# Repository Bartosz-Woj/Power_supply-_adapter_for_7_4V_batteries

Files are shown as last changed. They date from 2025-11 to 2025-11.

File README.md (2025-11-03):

# Custom Power Supply Adapter for 7.4V batteries

## Project Description

The idea of this project is to create a **simple adapter** that allows using a **9 V (or higher)** DC power source instead of the original **7.4 V Li-ion battery** — specifically for the **Panasonic Lumix G7 camera**, using the **DMW-DCC8 DC coupler**.

This solution provides a regulated **8.55 V / 2 A** output suitable for continuous camera operation without relying on battery power.

This PCB can be used to replace a battery/accumulator in other similar applications.

---

## Technical Specifications

| Parameter | Description |
| --- | --- |
| **Input Voltage**  | 9 V – 20 V DC |
| **Output Voltage** | 8.55 V DC |
| **Output Current** | 2 A (max) |
| **Protection** | Overcurrent fuse and ESD protection |
| **Connector** | Screw terminal connector (raster 5mm) |

---

## Battery Voltage Background

A typical **2S Li-ion battery pack** (used in cameras like the Lumix G7) has a **nominal voltage of 7.4 V**, but it varies depending on the charge level:

| Battery State | Approx. Voltage |
| --- | --- |
| Fully Discharged | 6.0 V |
| Nominal | 7.4 V |
| Fully Charged | 8.4 V |

Initially, a resistor **R6** (8.66 kOhm) was selected to provide an output of **7.4V**, targeting a nominal 7.4 V equivalent output.

However, this voltage caused the camera to display the error:

> _"This battery cannot be used."_

and automatically power off after a few seconds.

After further research and forum discussions [[thread 1](https://www.dpreview.com/forums/post/59409259)] [[thread 2](https://dprevived.com/t/panasonic-s-series-standby-power-updated-with-s5m2/4551/)], it was discovered that the **Lumix G7** expects a slightly higher voltage (over 8.4V) to correctly identify the source as an **external power supply** rather than a battery. The manufacturer's documentation did not specify the allowable maximum supply voltage. Therefore, it was decided to set the threshold only slightly above the maximum cell voltage.

Currenct consumption was checked with usage of laboratory power supply.The average current consumption is 0.3A, but momentary peaks, especially during startup and photo taking, reach above 1A.

---

## Adjustment of output voltage

The output voltage is determined by a resistor divider network:

$$
V_{\text{out}} = V_{\text{ref}}\left(1 + \dfrac{R_5}{R_6}\right)
$$

For used step down converter (TPS54202):
$$ V\_{ref} = 0.596\,V $$

Example values:
| R5 | R6 | Output voltage |
| --- | ---- | --- |
| 100k | 8.66k | 7.4V |
| 100k | 7.5k | 8.55V |

** Note:** The TVS diode's operating voltage sets the maximum output voltage at 8.55V.
---

## 📸 Photos

- **📷 Project Overview:**  
  Overview Photo

- **🔌 Circuit Board / PCB:**  
  PCB Photo

---

## Author

- **Project by:** Bartosz-Woj (Bartosz Wojciechowski)
- **Date:** 03.11.2025

---

## Disclaimer

> ⚠️ **Important Notice**

This project is a **custom-made modification** and **not approved by Panasonic** or any official manufacturer.  
Using this power adapter **may void your warranty** and **can potentially damage your device** if built or used incorrectly.

The author of this project **does not take responsibility** for any **damage, data loss, or warranty issues** resulting from the use of this adapter.

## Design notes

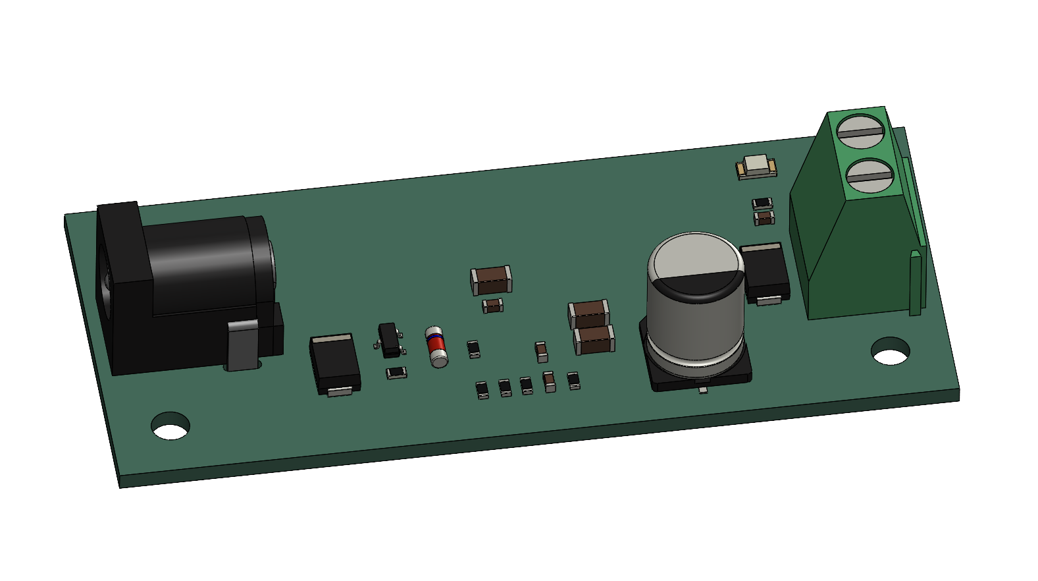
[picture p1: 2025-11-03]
photos/visualisation_PCB.png

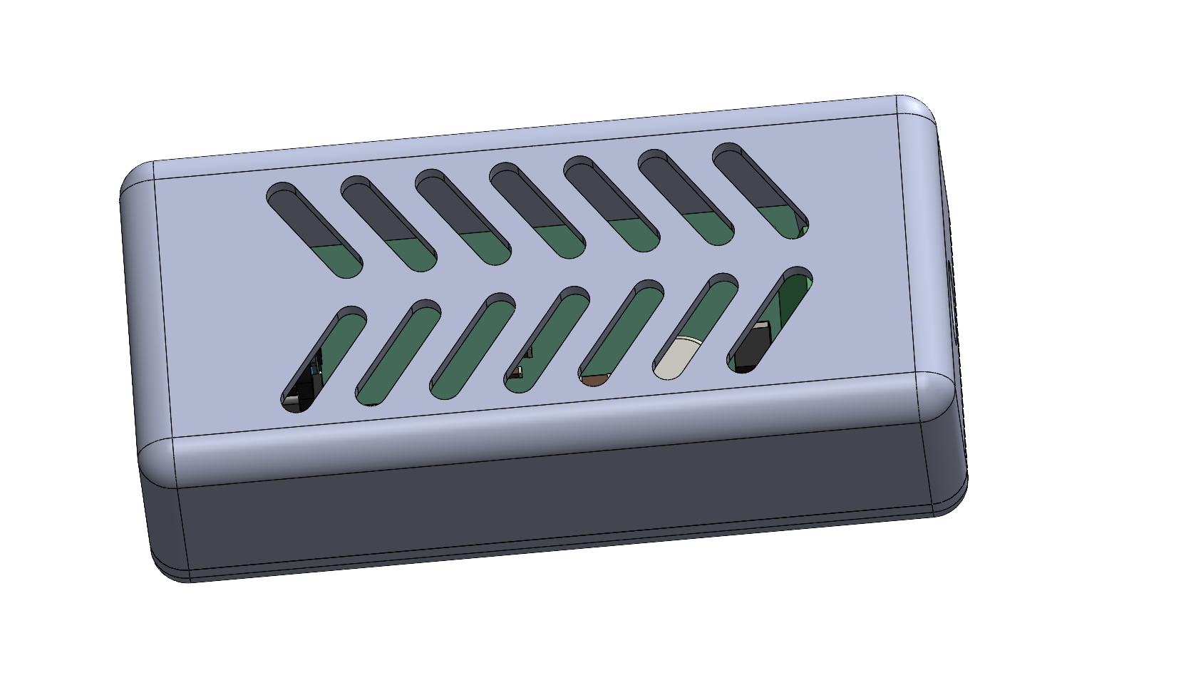
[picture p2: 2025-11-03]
photos/visualisation.png

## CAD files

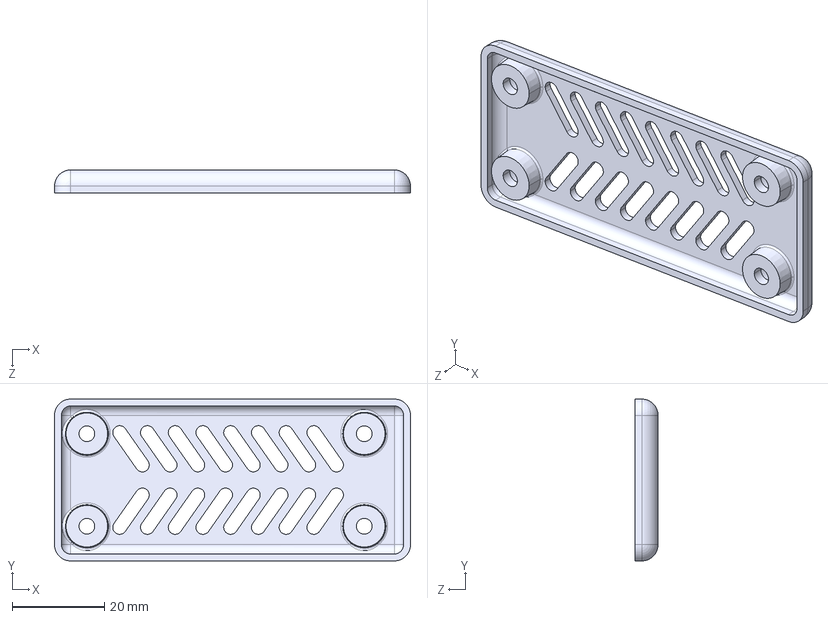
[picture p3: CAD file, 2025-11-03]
3D_cad_files/Bottom_case.STEP
77.0 x 35.0 x 5.00 mm

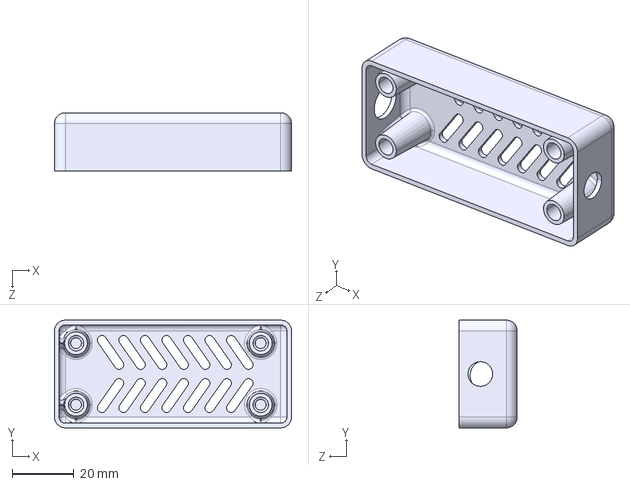
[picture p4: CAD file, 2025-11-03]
3D_cad_files/Top_case.STEP
77.0 x 35.0 x 19.0 mm

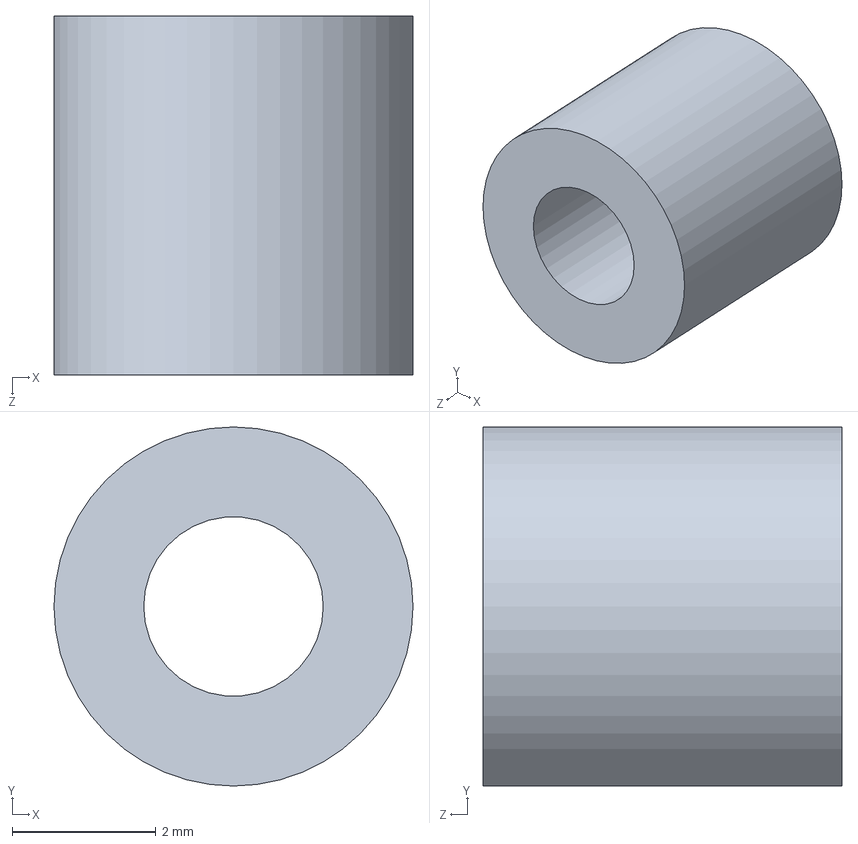
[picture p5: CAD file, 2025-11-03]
3D_cad_files/InsertM3.SLDPRT
5.00 x 5.00 x 5.00 mm

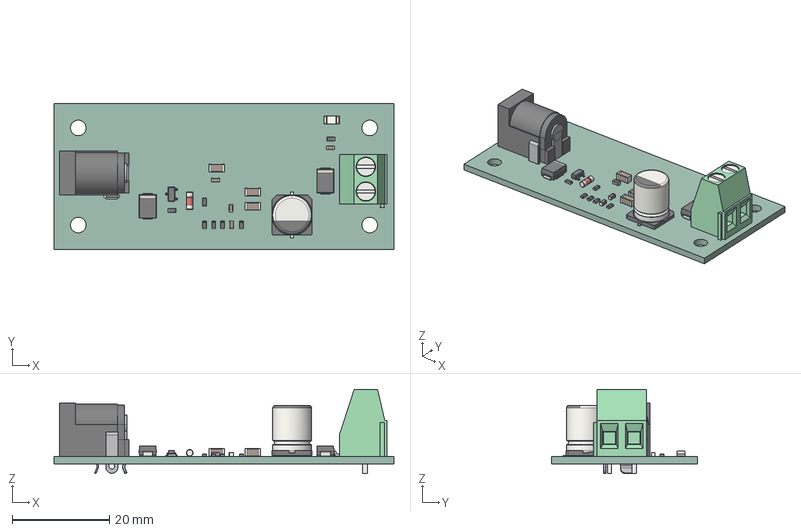
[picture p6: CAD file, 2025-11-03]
3D_cad_files/7_4V_battery_replacement.step
70.0 x 30.0 x 17.4 mm
BarrelJack_GCT_DCJ200-10-A_Horizontal
R_0603_1608Metric x 7
CP_Elec_8x10.5
C_1206_3216Metric x 3
D_SMB x 2
C_0603_1608Metric x 4
D_MiniMELF
LED_1206_3216Metric
TerminalBlock_Phoenix_MKDS-1,5-2-5.08_1x02_P5.08mm_Horizontal
SOT-23
Lumin_G7_battery_replacement_PCB

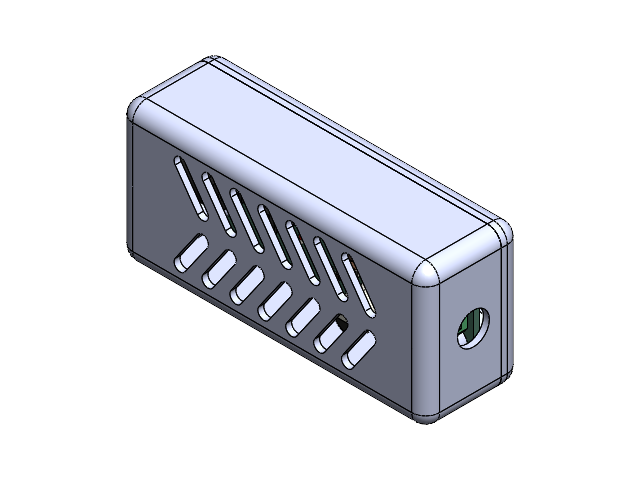
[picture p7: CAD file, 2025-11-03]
3D_cad_files/Assembly.SLDASM
Top_case
Bottom_case
InsertM3 x 4
BarrelJack_GCT_DCJ200-10-A_Horizontal.step
R_0603_1608Metric.step x 7
CP_Elec_8x10.5.step
C_1206_3216Metric.step x 3
D_SMB.step x 2
C_0603_1608Metric.step x 4
D_MiniMELF.step
LED_1206_3216Metric.step
TerminalBlock_Phoenix_MKDS-1,5-2-5.08_1x02_P5.08mm_Horizontal.step
SOT-23.step
Lumin_G7_battery_replacement_PCB.step

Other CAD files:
3D_cad_files/Bottom_case.SLDPRT
3D_cad_files/Bottom_case.STL
3D_cad_files/Top_case.SLDPRT
3D_cad_files/Top_case.STL

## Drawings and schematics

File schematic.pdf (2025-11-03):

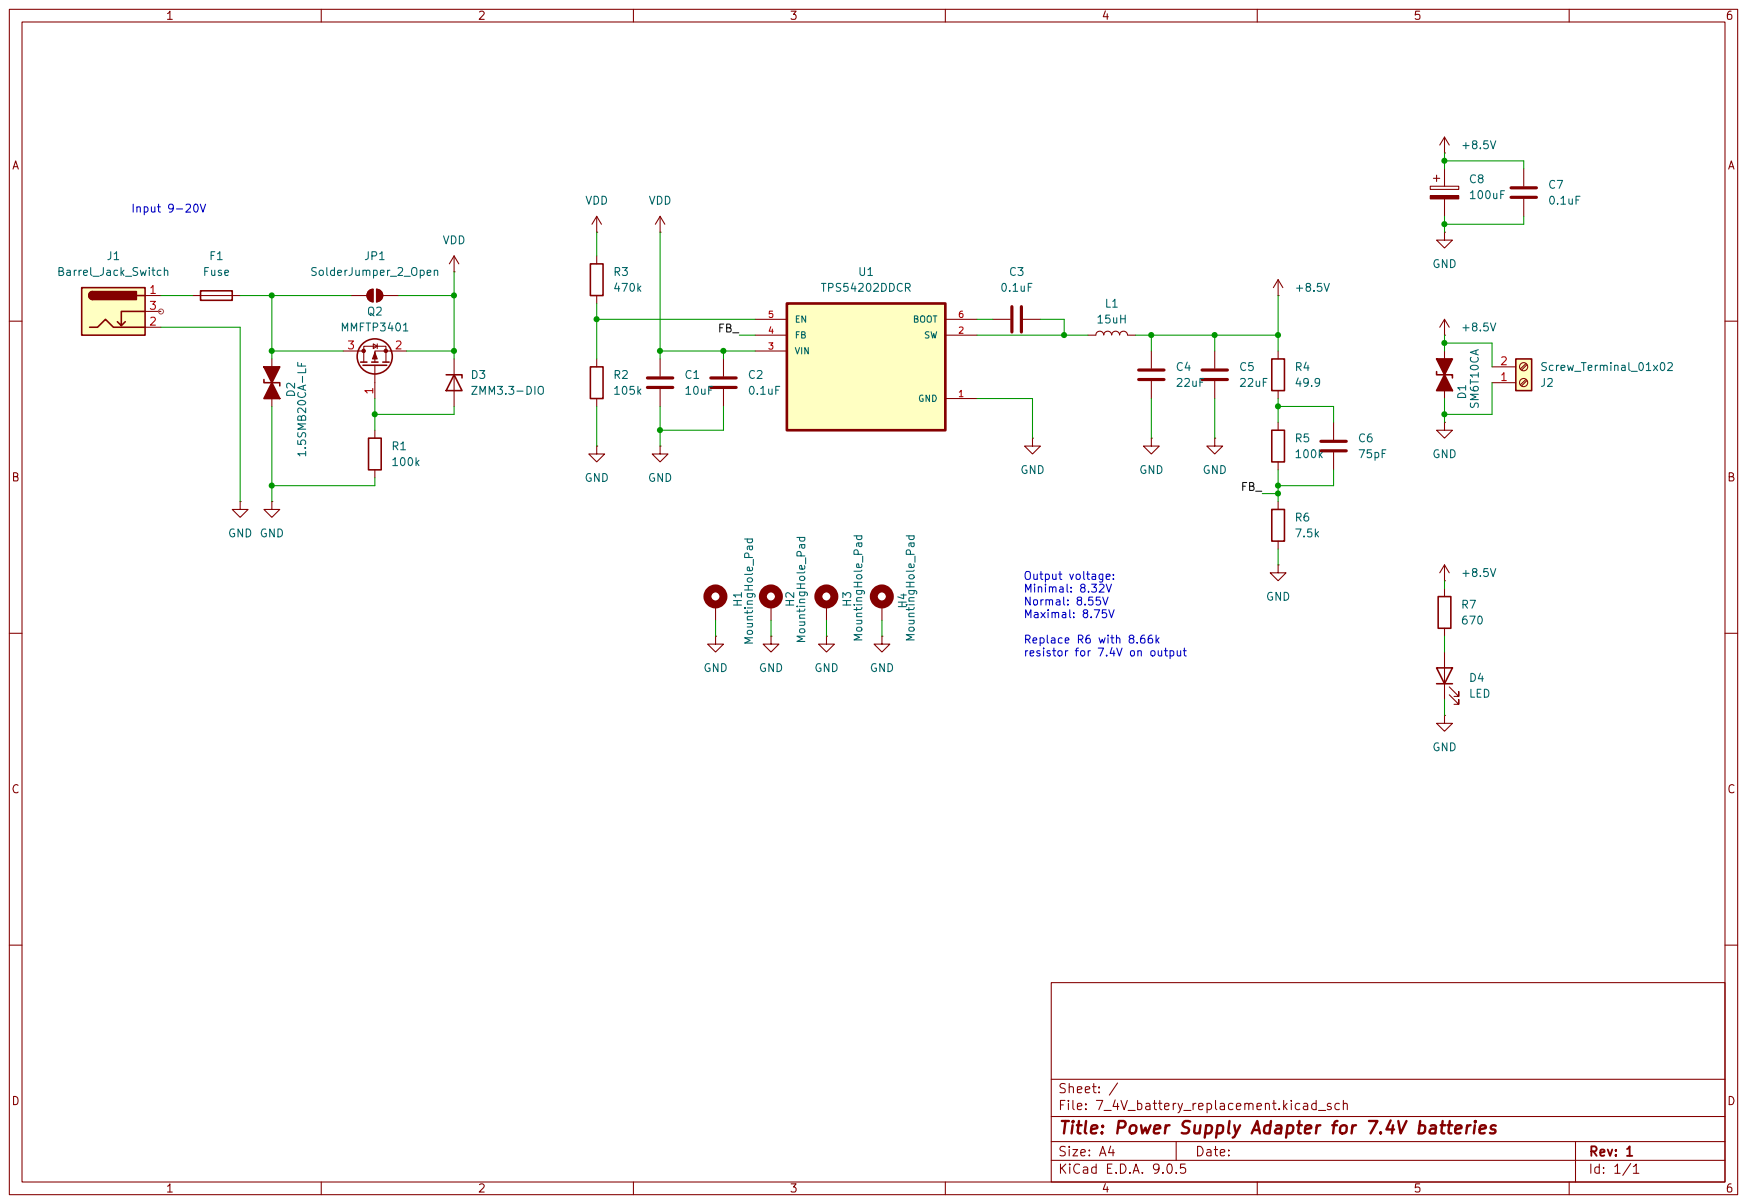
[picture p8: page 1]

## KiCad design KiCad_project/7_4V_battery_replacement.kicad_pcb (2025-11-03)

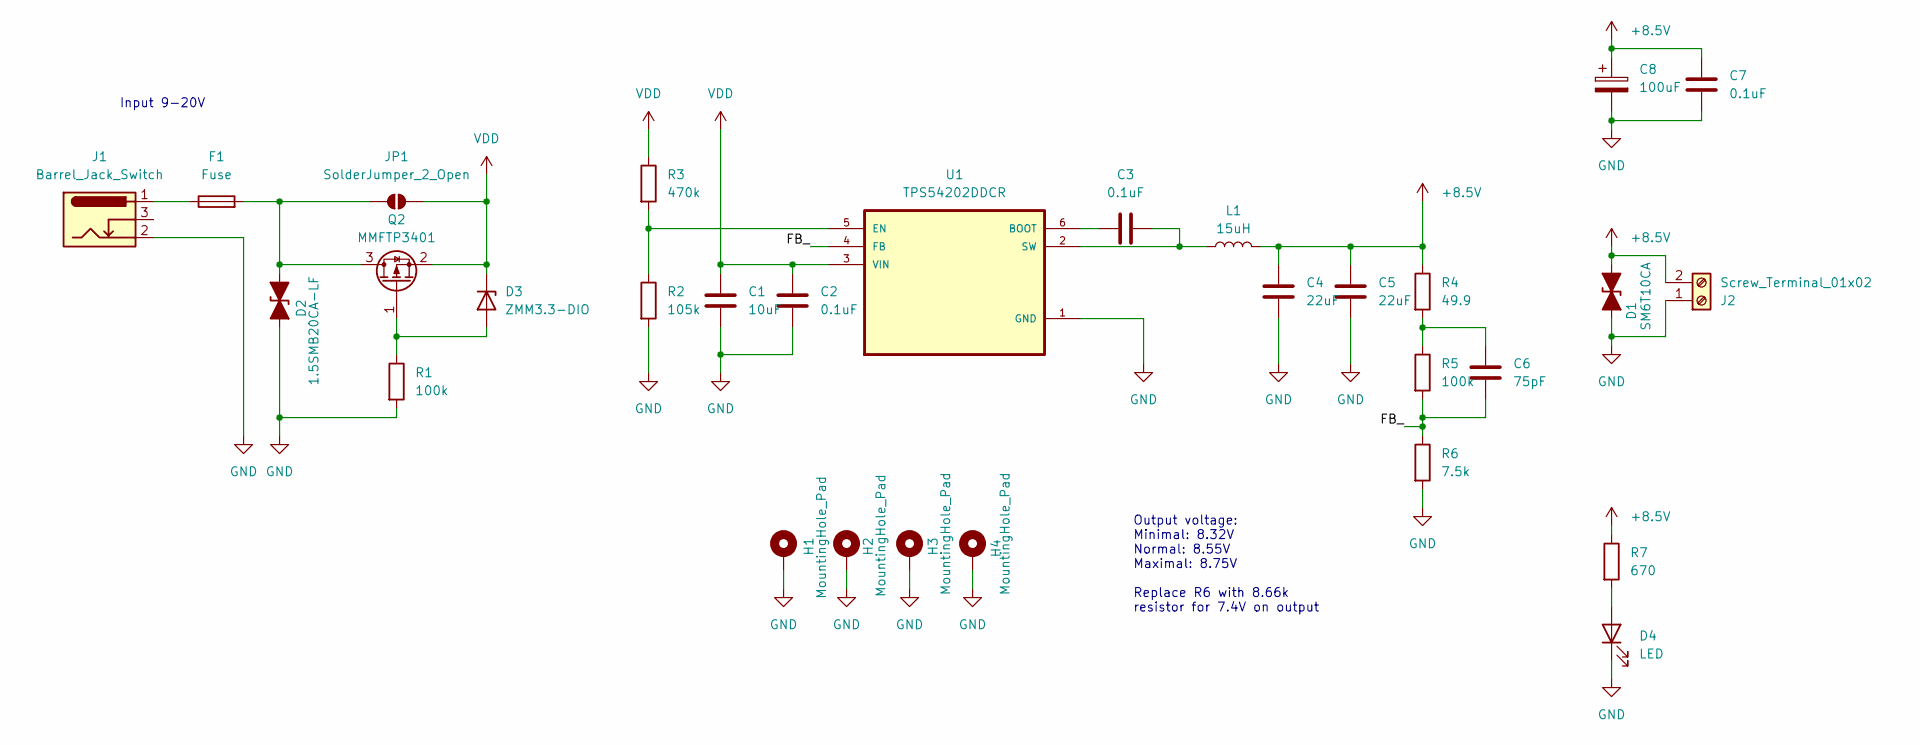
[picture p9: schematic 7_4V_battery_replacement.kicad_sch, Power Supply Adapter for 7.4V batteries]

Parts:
C1: 10uF; C_1206_3216Metric_Pad1.33x1.80mm_HandSolder
C2, C3, C7: 0.1uF; C_0603_1608Metric_Pad1.08x0.95mm_HandSolder
C4, C5: 22uF; C_1206_3216Metric_Pad1.33x1.80mm_HandSolder
C6: 75pF; C_0603_1608Metric_Pad1.08x0.95mm_HandSolder
C8: 100uF; CP_Elec_8x10.5
D1: SM6T10CA; D_SMB_Handsoldering
D2: 1.5SMB20CA-LF; D_SMB_Handsoldering
D3: ZMM3.3-DIO; D_MiniMELF
D4: LED; LED_1206_3216Metric_Pad1.42x1.75mm_HandSolder
F1: Fuse; Fuseholder_Littelfuse_Nano2_154x
H1, H2, H3, H4: MountingHole_Pad; MountingHole_3.2mm_M3_DIN965_Pad_TopBottom
J1: Barrel_Jack_Switch; BarrelJack_GCT_DCJ200-10-A_Horizontal
J2: Screw_Terminal_01x02; TerminalBlock_Phoenix_MKDS-1,5-2-5.08_1x02_P5.08mm_Horizont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
JP1: SolderJumper_2_Open; SolderJumper-2_P1.3mm_Open_RoundedPad1.0x1.5mm
L1: 15uH; L_Bourns_SRR1208_12.7x12.7mm
Q2: MMFTP3401; SOT-23
R1, R5: 100k; R_0603_1608Metric_Pad0.98x0.95mm_HandSolder
R2: 105k; R_0603_1608Metric_Pad0.98x0.95mm_HandSolder
R3: 470k; R_0603_1608Metric_Pad0.98x0.95mm_HandSolder
R4: 49.9; R_0603_1608Metric_Pad0.98x0.95mm_HandSolder
R6: 7.5k; R_0603_1608Metric_Pad0.98x0.95mm_HandSolder
R7: 670; R_0603_1608Metric_Pad0.98x0.95mm_HandSolder
U1: TPS54202DDCR; SOT95P280X110-6N

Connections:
+8.5V: C4.1, C5.1, C7.1, C8.1, D1.1 (A1), J2.2, L1.2, R4.1, R7.1
/FB_: C6.2, R5.2, R6.1, U1.4 (FB)
GND: C1.2, C2.2, C4.2, C5.2, C7.2, C8.2, D1.2 (A2), D2.2 (A2), D4.1 (K), H1.1, H2.1, H3.1, H4.1, J1.2, J2.1, R1.2, R2.2, R6.2, U1.1 (GND)
unnamed: C6.1, R4.2, R5.1
unnamed: D2.1 (A1), F1.2, JP1.1 (A), Q2.3 (D)
unnamed: D3.2 (A), Q2.1 (G), R1.1
unnamed: D4.2 (A), R7.2
unnamed: F1.1, J1.1
unnamed: C3.1, U1.6 (BOOT)
unnamed: R2.1, R3.2, U1.5 (EN)
unnamed: C3.2, L1.1, U1.2 (SW)
VDD: C1.1, C2.1, D3.1 (K), JP1.2 (B), Q2.2 (S), R3.1, U1.3 (VIN)

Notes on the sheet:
Input 9-20V
Output voltage: Minimal: 8.32V Normal: 8.55V Maximal: 8.75V Replace R6 with 8.66k resistor for 7.4V on output

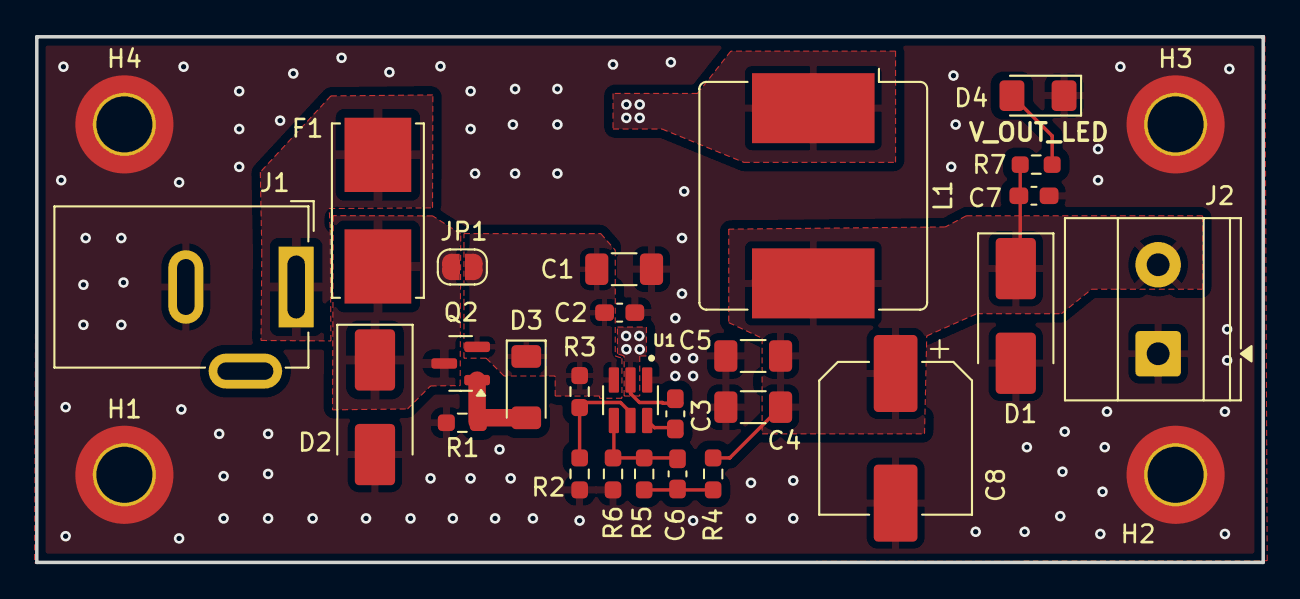
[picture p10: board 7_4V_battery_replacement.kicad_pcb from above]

Board: 2 copper layers, 70.0 x 30.0 mm, 30 parts (0 on the bottom side), 12 nets.
